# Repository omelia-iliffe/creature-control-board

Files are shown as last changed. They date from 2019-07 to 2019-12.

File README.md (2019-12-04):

# SECOND RELEASE COMING SOON
Open an issue to request features!

I am developing a circuit board for non-organic creatures.

#### Useful links:
Auto-Program circuit - https://arduino.stackexchange.com/questions/38012/major-difference-between-dtr-signal-and-rts-signal

| GPIO Determining the Boot Mode | | | |
|---|---|---|---|
| Pin | Default | Run Mode | Download Mode |
| IO0 | Pull-up | 1 | 0 |
| TXD0 | Pull-up | 1 | x |
| IO2 | Pull-down | x | 0 |
| IO5 | Pull-up | 1 | x |
(Table from https://www.sparkfun.com/news/2017)

Breakout Board for LSM6DS3 - https://github.com/sparkfun/LSM6DS3_Breakout
https://learn.sparkfun.com/tutorials/lsm6ds3-breakout-hookup-guide

Breakout Board for TPA2005D1 - https://github.com/sparkfun/Mono_Audio_Amp_Breakout-TPA2005D1
http://cdn.sparkfun.com/datasheets/BreakoutBoards/Mono%20Audio%20Amp%20TPA2005D1%20v10.pdf

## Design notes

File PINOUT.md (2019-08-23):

## Left Headers
3.3V
23
22 / SCL
TXD1
RXD1
21 / SDA
19 / IMUINT2
18 / IMUINT1
5 / LED
17 / TXD2
16 / RXD2
4
0
2
15
GND

## Right Headers
GND
VP / BATSTAT
VN / BATLEVEL
34 / GROVE2
35 / GROVE2
32 / GROVE1
33 / GROVE1
25 / AMP_IN
26
27 / AMP_EN
14
12
13
GND
VBAT
3.3V

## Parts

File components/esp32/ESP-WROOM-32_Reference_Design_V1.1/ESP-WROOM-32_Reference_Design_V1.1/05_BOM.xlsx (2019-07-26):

Item | Quantity | Reference | Specifications
1 | 2 | C1, C2 | 22 pF ± 5%/50 V, 0402
2 | 1 | C3 | 100 pF ± 5%/50 V, 0402
3 | 4 | C4, C9, C10, C19 | 0.1 uF ± 10%/10 V, 0402
4 | 1 | C5 | 10 nF ± 10%/6.3 V, 0402
5 | 1 | C6 | 3.3 nF ± 10%/50 V, 0402
6 | 3 | C11, C18, C20 | 1 uF ± 10%/16 V, 0402
7 | 0 | C12 | NC
8 | 1 | C13 | 10 uF ± 20%/6.3 V, 0603
9 | 1 | C14 | GRM1555C1H4R7BA01D (4.7 pF ± 0.1 pF, 0402)
10 | 1 | C15 | GRM1555C1H2R4CA01D (2.4 pF ± 0.25 pF, 0402)
11 | 2 | C16, C17 | 270 pF ± 5%/50 V, 0402
12 | 1 | L4 | LQP15MN2N4B02D (2.4 nH ± 0.1 nH, 0402)
13 | 1 | D1 | ESD 3.3 V 88D-LCDN, DFN1006
14 | 1 | R1 | 20 K ± 1%/16 W, 0402
15 | 1 | U1 | 40 MHz Crystal, ±10 ppm, 3225
16 | 1 | U2 | ESP32, QFN48_6X6
17 | 1 | U3 | Flash, SOP8-208 mil, GD25Q32
* Please note that Murata is recommended for C14, C15 and L4 for good quality and accuracy.

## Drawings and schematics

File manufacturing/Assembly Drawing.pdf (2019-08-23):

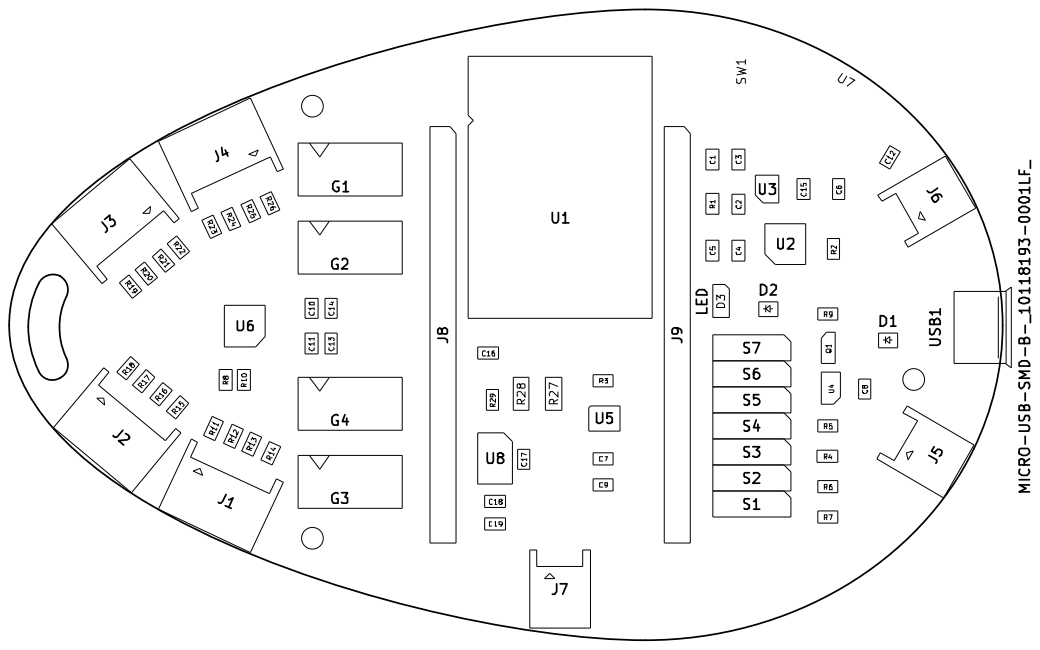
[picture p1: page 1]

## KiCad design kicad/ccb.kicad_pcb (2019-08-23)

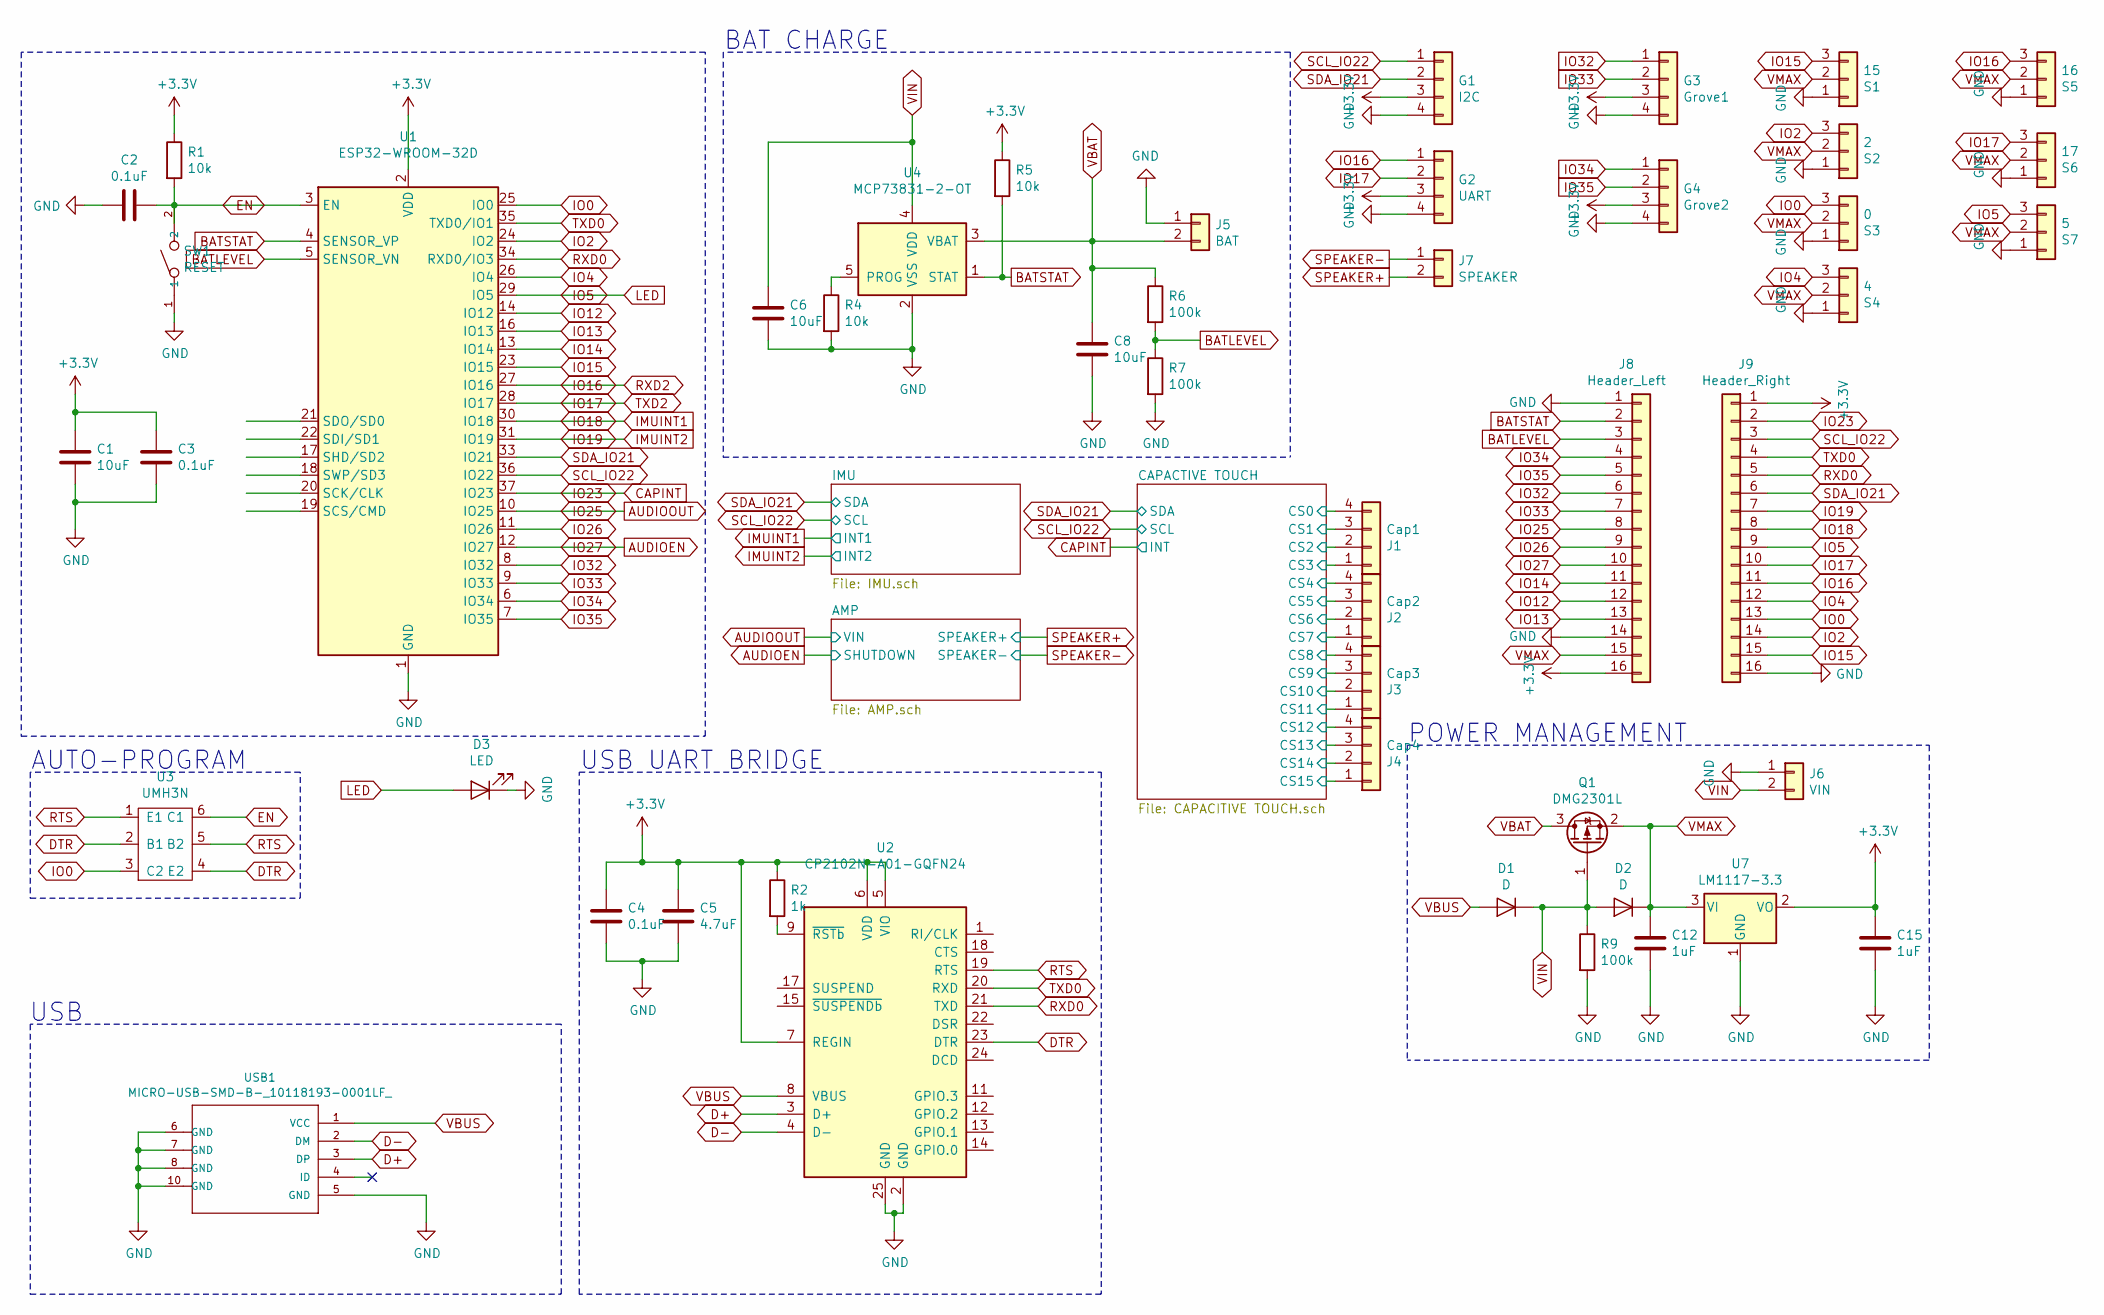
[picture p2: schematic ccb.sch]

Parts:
C1, C6, C8: 10uF; C_0805_2012Metric; MPN CL21A106KPFNNNE
C2, C3, C4: 0.1uF; C_0805_2012Metric; MPN CL21B104MACNNNC
C5: 4.7uF; C_0805_2012Metric; MPN CL21A475KPFNNNG
C12, C15: 1uF; C_0805_2012Metric; MPN CL21B105KOFNNNG
D1, D2: D; D_SOD-323; MPN BAT60JFILM
D3: LED; LED_1206_3216Metric_Pad1.42x1.75mm_HandSolder
G1: I2C; NS-Tech_Grove_1x04_P2mm_Vertical; MPN 110990030
G2: UART; NS-Tech_Grove_1x04_P2mm_Vertical; MPN 110990030
G3: Grove1; NS-Tech_Grove_1x04_P2mm_Vertical; MPN 110990030
G4: Grove2; NS-Tech_Grove_1x04_P2mm_Vertical; MPN 110990030
J1: Cap1; JST_PH_S4B-PH-K_1x04_P2.00mm_Horizontal; MPN S4B-PH-K-S(LF)(SN)
J2: Cap2; JST_PH_S4B-PH-K_1x04_P2.00mm_Horizontal; MPN S4B-PH-K-S(LF)(SN)
J3: Cap3; JST_PH_S4B-PH-K_1x04_P2.00mm_Horizontal; MPN S4B-PH-K-S(LF)(SN)
J4: Cap4; JST_PH_S4B-PH-K_1x04_P2.00mm_Horizontal; MPN S4B-PH-K-S(LF)(SN)
J5: BAT; JST_PH_S2B-PH-K_1x02_P2.00mm_Horizontal; MPN S2B-PH-K-S(LF)(SN)
J6: VIN; JST_PH_S2B-PH-K_1x02_P2.00mm_Horizontal; MPN S2B-PH-K-S(LF)(SN)
J7: SPEAKER; JST_PH_S2B-PH-K_1x02_P2.00mm_Horizontal; MPN S2B-PH-K-S(LF)(SN)
J8: Header_Left; PinSocket_1x16_P2.54mm_Vertical; MPN 0022032161
J9: Header_Right; PinSocket_1x16_P2.54mm_Vertical; MPN 0022032161
Q1: DMG2301L; SOT-23; MPN NTR3A052PZT1G
R1, R4, R5: 10k; R_0805_2012Metric; MPN RMCF0805FT10K0
R2: 1k; R_0805_2012Metric; MPN RMCF0805FT1K00
R6, R7, R9: 100k; R_0805_2012Metric; MPN RMCF0805FT100K
S1: 15; PinHeader_1x03_P2.54mm_Vertical; MPN WM4001-ND
S2: 2; PinHeader_1x03_P2.54mm_Vertical; MPN WM4001-ND
S3: 0; PinHeader_1x03_P2.54mm_Vertical; MPN WM4001-ND
S4: 4; PinHeader_1x03_P2.54mm_Vertical; MPN WM4001-ND
S5: 16; PinHeader_1x03_P2.54mm_Vertical; MPN WM4001-ND
S6: 17; PinHeader_1x03_P2.54mm_Vertical; MPN WM4001-ND
S7: 5; PinHeader_1x03_P2.54mm_Vertical; MPN WM4001-ND
SW1: RESET; SW2-2.6-3.0X2.5X1.2+0.4MM; MPN B3U-1000P
U1: ESP32-WROOM-32D; ESP32-WROOM-32; MPN ESP32-WROOM-32D
U2: CP2102N-A01-GQFN24; QFN-24-1EP_4x4mm_P0.5mm_EP2.6x2.6mm; MPN CP2102N-A02-GQFN24R
U3: UMH3N; MPN UMH3NTN
U4: MCP73831-2-OT; SOT-23-5; MPN MCP73831T-2ACI/OT
U7: LM1117-3.3; TO-252; MPN LM1117IMPX-3.3/NOPB
USB1: MICRO-USB-SMD-B-_10118193-0001LF_; MICRO-USB5+6P-SMD-0.65-B; MPN 10118193-0001LF

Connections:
+3V3: C1.2, C3.2, C4.2, C5.2, C15.2, G1.3, G2.3, G3.3, G4.3, J8.16, J9.1, R1.1, R2.1, R5.1, U1.2 (VDD), U2.5 (VIO), U2.6 (VDD), U2.7 (REGIN), U7.2 (VO); also elsewhere on the board
/CAPACTIVE TOUCH/CS0: J1.4; also elsewhere on the board
/CAPACTIVE TOUCH/CS1: J1.3; also elsewhere on the board
/CAPACTIVE TOUCH/CS2: J1.2; also elsewhere on the board
/CAPACTIVE TOUCH/CS3: J1.1; also elsewhere on the board
/CAPACTIVE TOUCH/CS4: J2.4; also elsewhere on the board
/CAPACTIVE TOUCH/CS5: J2.3; also elsewhere on the board
/CAPACTIVE TOUCH/CS6: J2.2; also elsewhere on the board
/CAPACTIVE TOUCH/CS7: J2.1; also elsewhere on the board
/CAPACTIVE TOUCH/CS8: J3.4; also elsewhere on the board
/CAPACTIVE TOUCH/CS9: J3.3; also elsewhere on the board
/CAPACTIVE TOUCH/CS10: J3.2; also elsewhere on the board
/CAPACTIVE TOUCH/CS11: J3.1; also elsewhere on the board
/CAPACTIVE TOUCH/CS12: J4.4; also elsewhere on the board
/CAPACTIVE TOUCH/CS13: J4.3; also elsewhere on the board
/CAPACTIVE TOUCH/CS14: J4.2; also elsewhere on the board
/CAPACTIVE TOUCH/CS15: J4.1; also elsewhere on the board
AUDIOEN: J8.10, U1.12 (IO27); also elsewhere on the board
AUDIOOUT: J8.8, U1.10 (IO25); also elsewhere on the board
BATLEVEL: J8.3, R6.2, R7.1, U1.5 (SENSOR_VN)
BATSTAT: J8.2, R5.2, U1.4 (SENSOR_VP), U4.1 (STAT)
CAPINT: J9.2, U1.37 (IO23); also elsewhere on the board
D+: U2.3 (D+), USB1.3 (DP)
D-: U2.4 (D-), USB1.2 (DM)
DTR: U2.23 (DTR), U3.2 (B1), U3.4 (E2)
EN: C2.1, R1.2, SW1.2, U1.3 (EN), U3.6 (C1)
GND: C1.1, C2.2, C3.1, C4.1, C5.1, C6.1, C8.1, C12.1, C15.1, D3.1 (K), G1.4, G2.4, G3.4, G4.4, J5.1, J6.1, J8.1, J8.14, J9.16, R4.2, R7.2, R9.2, S1.1, S2.1, S3.1, S4.1, S5.1, S6.1, S7.1, SW1.1, U1.1 (GND), U1.15 (GND), U1.38 (GND), U2.2 (GND), U2.25 (GND), U4.2 (VSS), U7.1 (GND), USB1.5 (GND), USB1.6 (GND), USB1.7 (GND), USB1.8 (GND), USB1.9 (GND), USB1.10 (GND), USB1.11 (GND); also elsewhere on the board
IMUINT1: J9.8, U1.30 (IO18); also elsewhere on the board
IMUINT2: J9.7, U1.31 (IO19); also elsewhere on the board
IO0: J9.13, S3.3, U1.25 (IO0), U3.3 (C2)
IO2: J9.14, S2.3, U1.24 (IO2)
IO4: J9.12, S4.3, U1.26 (IO4)
IO5: D3.2 (A), J9.9, S7.3, U1.29 (IO5)
IO12: J8.12, U1.14 (IO12)
IO13: J8.13, U1.16 (IO13)
IO14: J8.11, U1.13 (IO14)
IO15: J9.15, S1.3, U1.23 (IO15)
IO16: G2.1, J9.11, S5.3, U1.27 (IO16)
IO17: G2.2, J9.10, S6.3, U1.28 (IO17)
IO26: J8.9, U1.11 (IO26)
IO32: G3.1, J8.6, U1.8 (IO32)
IO33: G3.2, J8.7, U1.9 (IO33)
IO34: G4.1, J8.4, U1.6 (IO34)
IO35: G4.2, J8.5, U1.7 (IO35)
unnamed: R2.2, U2.9 (~RSTb)
unnamed: R4.1, U4.5 (PROG)
RTS: U2.19 (RTS), U3.1 (E1), U3.5 (B2)
RXD0: J9.5, U1.34 (RXD0/IO3), U2.21 (TXD)
SCL_IO22: G1.1, J9.3, U1.36 (IO22); also elsewhere on the board
SDA_IO21: G1.2, J9.6, U1.33 (IO21); also elsewhere on the board
SPEAKER+: J7.2; also elsewhere on the board
SPEAKER-: J7.1; also elsewhere on the board
TXD0: J9.4, U1.35 (TXD0/IO1), U2.20 (RXD)
VBAT: C8.2, J5.2, Q1.3 (D), R6.1, U4.3 (VBAT)
VBUS: D1.2 (A), U2.8 (VBUS), USB1.1 (VCC)
VIN: C6.2, D1.1 (K), D2.2 (A), J6.2, Q1.1 (G), R9.1, U4.4 (VDD)
VMAX: C12.2, D2.1 (K), J8.15, Q1.2 (S), S1.2, S2.2, S3.2, S4.2, S5.2, S6.2, S7.2, U7.3 (VI)

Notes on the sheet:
USB
USB UART BRIDGE
AUTO-PROGRAM
BAT CHARGE
POWER MANAGEMENT

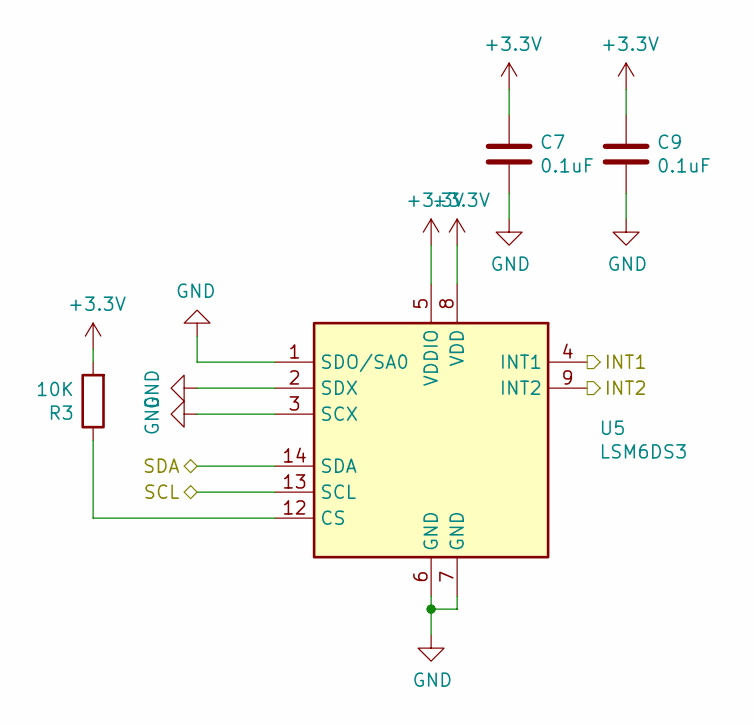
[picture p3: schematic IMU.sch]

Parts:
C7, C9: 0.1uF; C_0805_2012Metric; MPN CL21B104MACNNNC
R3: 10K; R_0805_2012Metric; MPN RMCF0805FT10K0
U5: LSM6DS3; LGA-14L_2.5x3mm__LSM6DS3; MPN LSM6DS3TR

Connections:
+3V3: C7.2, C9.2, R3.2, U5.5 (VDDIO), U5.8 (VDD); also elsewhere on the board
GND: C7.1, C9.1, U5.1 (SDO/SA0), U5.2 (SDX), U5.3 (SCX), U5.6 (GND), U5.7 (GND); also elsewhere on the board
IMUINT1: U5.4 (INT1); also elsewhere on the board
IMUINT2: U5.9 (INT2); also elsewhere on the board
unnamed: R3.1, U5.12 (CS)
SCL_IO22: U5.13 (SCL); also elsewhere on the board
SDA_IO21: U5.14 (SDA); also elsewhere on the board

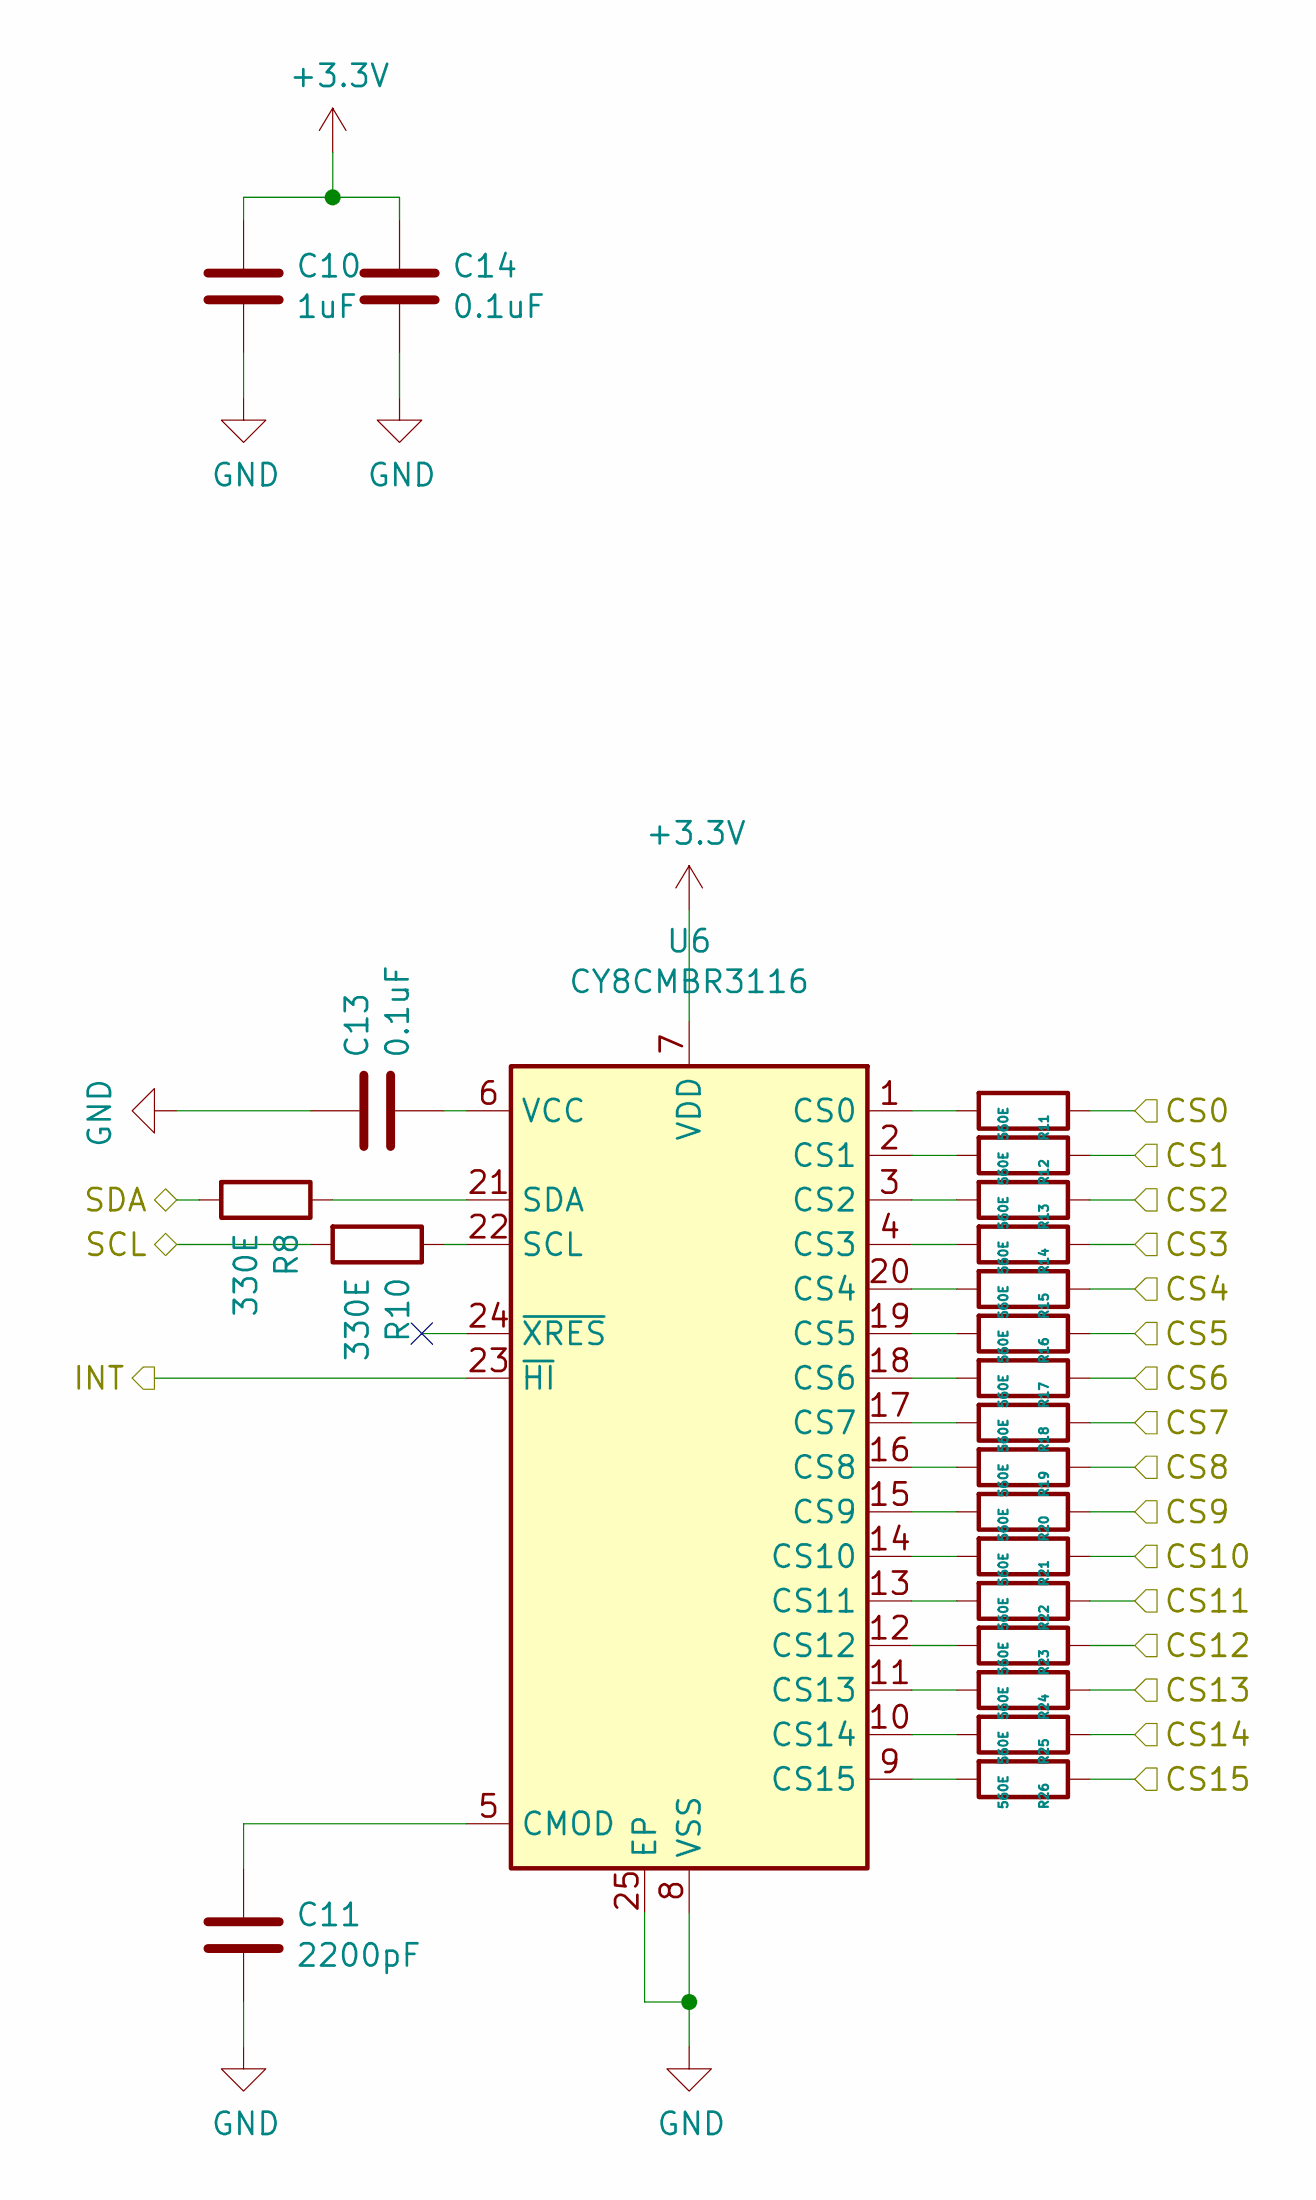
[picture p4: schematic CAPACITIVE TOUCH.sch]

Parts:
C10: 1uF; C_0805_2012Metric; MPN CL21B105KOFNNNG
C11: 2200pF; C_0805_2012Metric; MPN CL21B222JBANNNC
C13, C14: 0.1uF; C_0805_2012Metric; MPN CL21B104MACNNNC
R8, R10: 330E; R_0805_2012Metric; MPN RMCF0805FT330R
R11, R12, R13, R14, R15, R16, R17, R18, R19, R20, R21, R22, R23, R24, R25, R26: 560E; R_0805_2012Metric; MPN RMCF1206JG560R
U6: CY8CMBR3116; QFN-24-1EP_4x4mm_P0.5mm_EP2.6x2.6mm; MPN CY8CMBR3116

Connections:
+3V3: C10.2, C14.2, U6.7 (VDD); also elsewhere on the board
/CAPACTIVE TOUCH/CS0: R11.1; also elsewhere on the board
/CAPACTIVE TOUCH/CS1: R12.1; also elsewhere on the board
/CAPACTIVE TOUCH/CS2: R13.1; also elsewhere on the board
/CAPACTIVE TOUCH/CS3: R14.1; also elsewhere on the board
/CAPACTIVE TOUCH/CS4: R15.1; also elsewhere on the board
/CAPACTIVE TOUCH/CS5: R16.1; also elsewhere on the board
/CAPACTIVE TOUCH/CS6: R17.1; also elsewhere on the board
/CAPACTIVE TOUCH/CS7: R18.1; also elsewhere on the board
/CAPACTIVE TOUCH/CS8: R19.1; also elsewhere on the board
/CAPACTIVE TOUCH/CS9: R20.1; also elsewhere on the board
/CAPACTIVE TOUCH/CS10: R21.1; also elsewhere on the board
/CAPACTIVE TOUCH/CS11: R22.1; also elsewhere on the board
/CAPACTIVE TOUCH/CS12: R23.1; also elsewhere on the board
/CAPACTIVE TOUCH/CS13: R24.1; also elsewhere on the board
/CAPACTIVE TOUCH/CS14: R25.1; also elsewhere on the board
/CAPACTIVE TOUCH/CS15: R26.1; also elsewhere on the board
CAPINT: U6.23 (~HI); also elsewhere on the board
GND: C10.1, C11.1, C13.2, C14.1, U6.8 (VSS), U6.25 (EP); also elsewhere on the board
unnamed: C11.2, U6.5 (CMOD)
unnamed: C13.1, U6.6 (VCC)
unnamed: R8.1, U6.21 (SDA)
unnamed: R10.1, U6.22 (SCL)
unnamed: R11.2, U6.1 (CS0)
unnamed: R12.2, U6.2 (CS1)
unnamed: R13.2, U6.3 (CS2)
unnamed: R14.2, U6.4 (CS3)
unnamed: R15.2, U6.20 (CS4)
unnamed: R16.2, U6.19 (CS5)
unnamed: R17.2, U6.18 (CS6)
unnamed: R18.2, U6.17 (CS7)
unnamed: R19.2, U6.16 (CS8)
unnamed: R20.2, U6.15 (CS9)
unnamed: R21.2, U6.14 (CS10)
unnamed: R22.2, U6.13 (CS11)
unnamed: R23.2, U6.12 (CS12)
unnamed: R24.2, U6.11 (CS13)
unnamed: R25.2, U6.10 (CS14)
unnamed: R26.2, U6.9 (CS15)
SCL_IO22: R10.2; also elsewhere on the board
SDA_IO21: R8.2; also elsewhere on the board

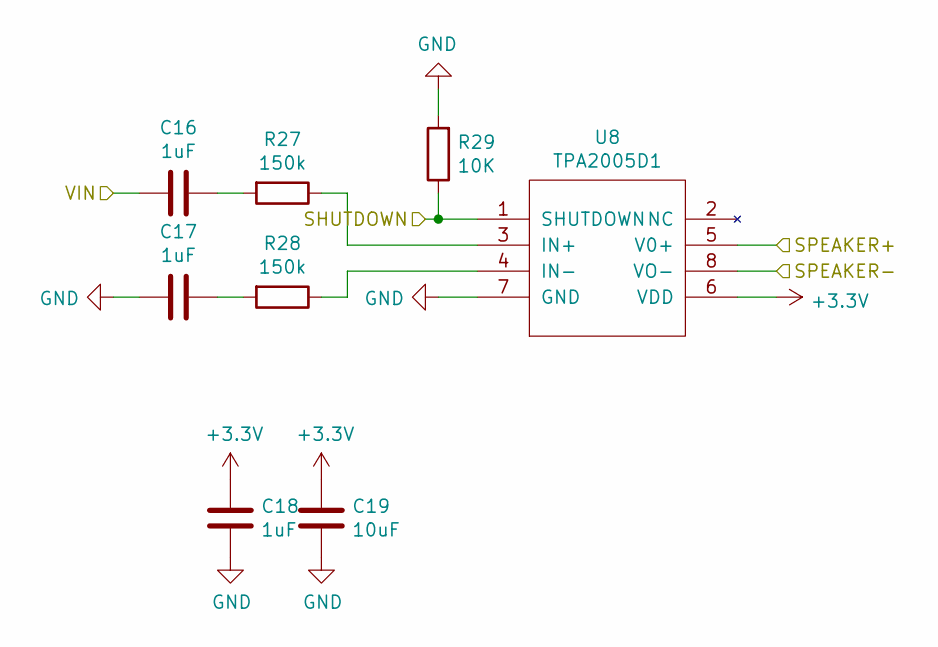
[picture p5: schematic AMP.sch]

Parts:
C16, C17, C18: 1uF; C_0805_2012Metric; MPN CL21B105KOFNNNG
C19: 10uF; C_0805_2012Metric; MPN CL21A106KPFNNNE
R27, R28: 150k; R_1206_3216Metric_Pad1.42x1.75mm_HandSolder; MPN RMCF1206FT150K
R29: 10K; R_0805_2012Metric; MPN RMCF0805FT10K0
U8: TPA2005D1; MPN TPA2005D1DGNR

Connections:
+3V3: C18.1, C19.1, U8.6 (VDD); also elsewhere on the board
AUDIOEN: R29.1, U8.1 (SHUTDOWN); also elsewhere on the board
AUDIOOUT: C16.1; also elsewhere on the board
GND: C17.1, C18.2, C19.2, R29.2, U8.7 (GND); also elsewhere on the board
unnamed: C16.2, R27.2
unnamed: C17.2, R28.2
unnamed: R27.1, U8.3 (IN+)
unnamed: R28.1, U8.4 (IN-)
SPEAKER+: U8.5 (V0+); also elsewhere on the board
SPEAKER-: U8.8 (VO-); also elsewhere on the board

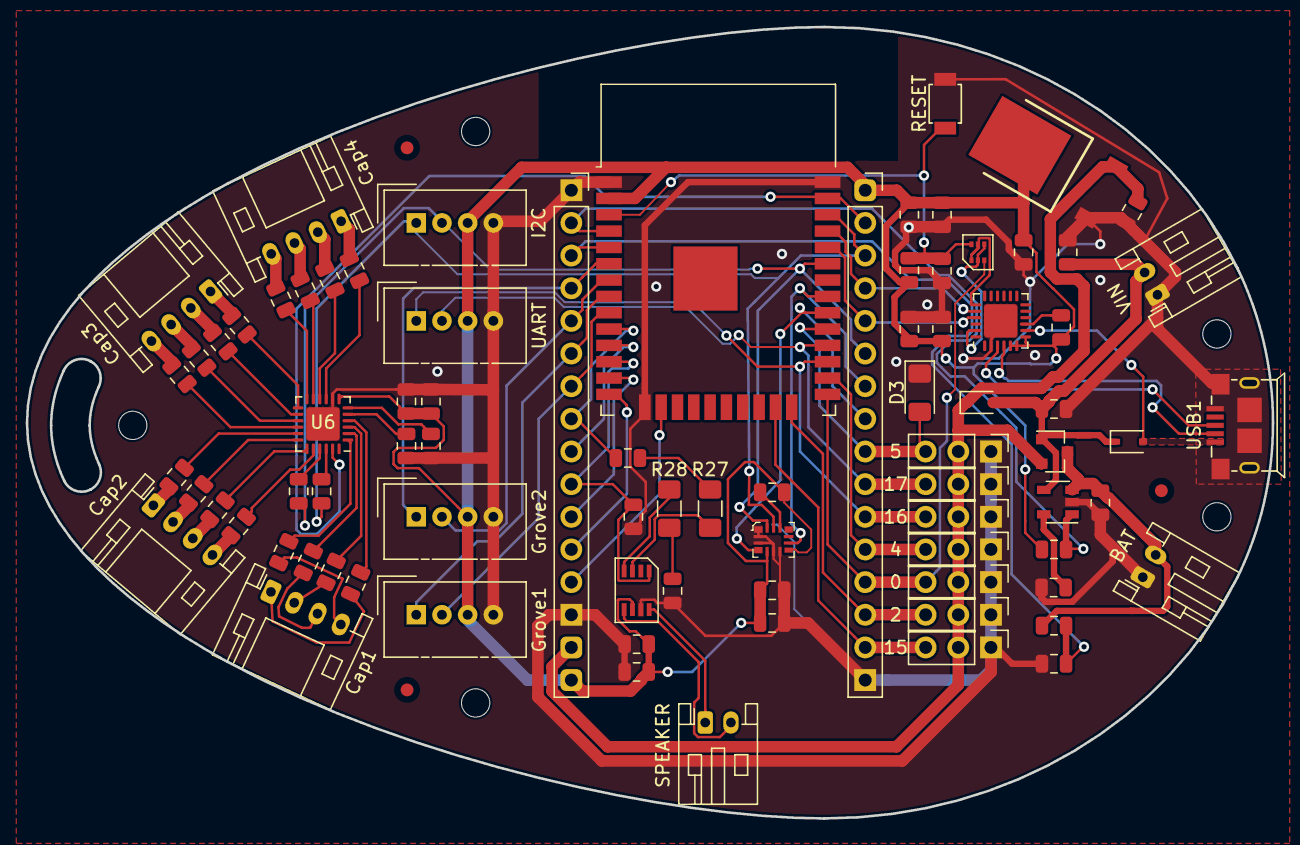
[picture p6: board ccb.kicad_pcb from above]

Board: 2 copper layers, 96.9 x 61.6 mm, 82 parts (0 on the bottom side), 82 nets.

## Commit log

2019-07-26 completed esp32 basic layout
    [05_BOM.xlsx, SCH_ESP_WROOM_32_6X6.DSN, bom.xlsx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]
2019-07-27 added CY8CMBR3116, LSM6DS3
    [ccb.sch]
2019-08-09 completed inital layout
    [AMP.sch, CAPACITIVE TOUCH.sch, CY8CMBR3xxx_Design_Toolbox.xlsx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]
2019-08-11 updated bom
    [bom.xlsx, ccb.kicad_pcb]
2019-08-11 updated gitignore
    [SCH_ESP_WROOM_32_6X6.DSN]
2019-08-15 laying out board
    [AMP.sch, IMU.sch, bom.xlsx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]
2019-08-18 completed layout (xh connectors)
    [ccb.kicad_pcb]
2019-08-20 completed egg layout (final)
    [AMP.sch, CAPACITIVE TOUCH.sch, IMU.sch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]
2019-08-23 added silkscreen, and manufacturing files
    [AMP.sch, IMU.sch, bom.xlsx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]
